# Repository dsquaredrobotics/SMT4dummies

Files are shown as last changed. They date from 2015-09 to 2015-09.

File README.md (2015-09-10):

# SMT4dummies

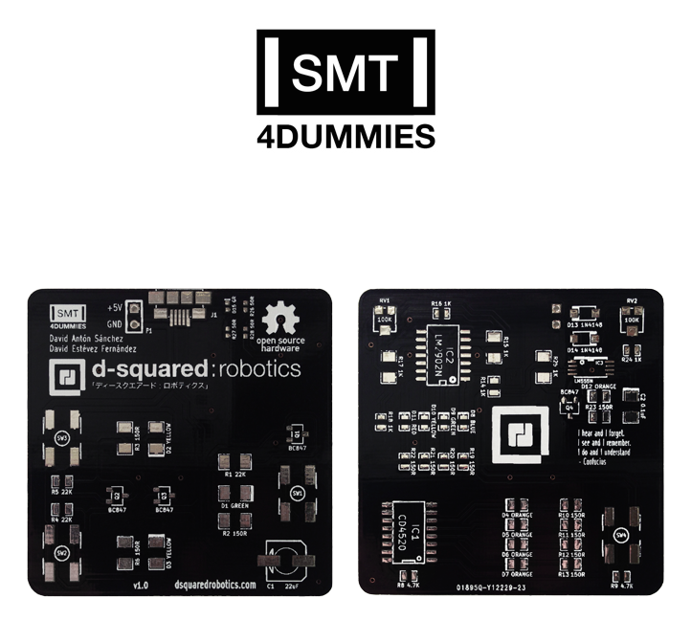
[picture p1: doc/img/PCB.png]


####Project

SMT4dummies is an SMT soldering practice kit.

###More info on [d-dquared:robotics](http://www.dsquaredrobotics.com/projects/smt4dummies/)

###Get one SMT4dummies kit on our [Store!](http://dsquaredrobotics.bigcartel.com/products)

Published under a GPLv3 lincense. More details on LICENSE.txt

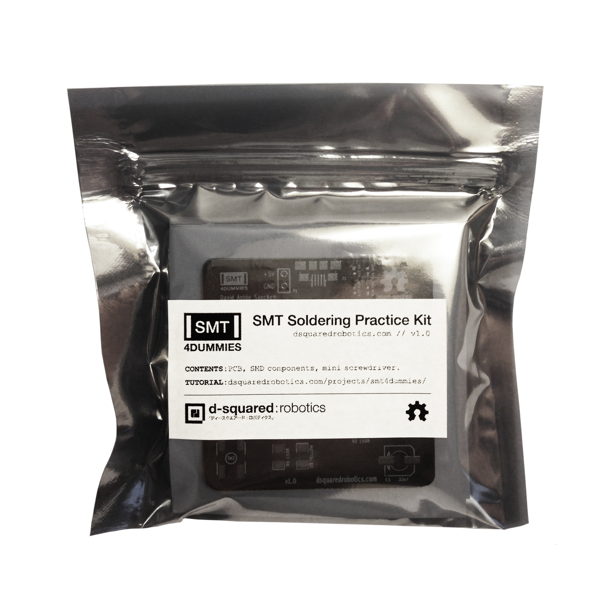
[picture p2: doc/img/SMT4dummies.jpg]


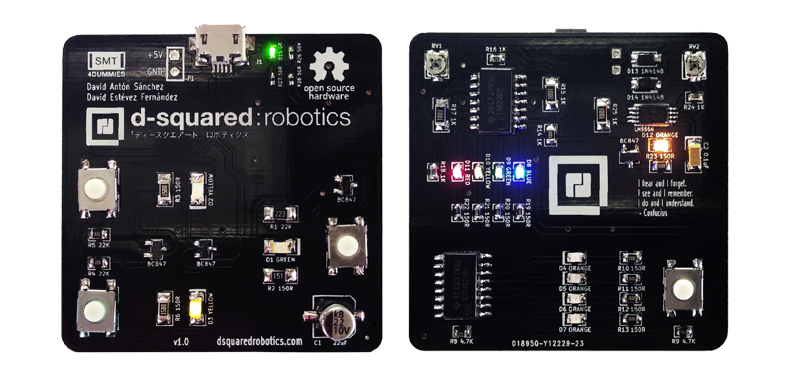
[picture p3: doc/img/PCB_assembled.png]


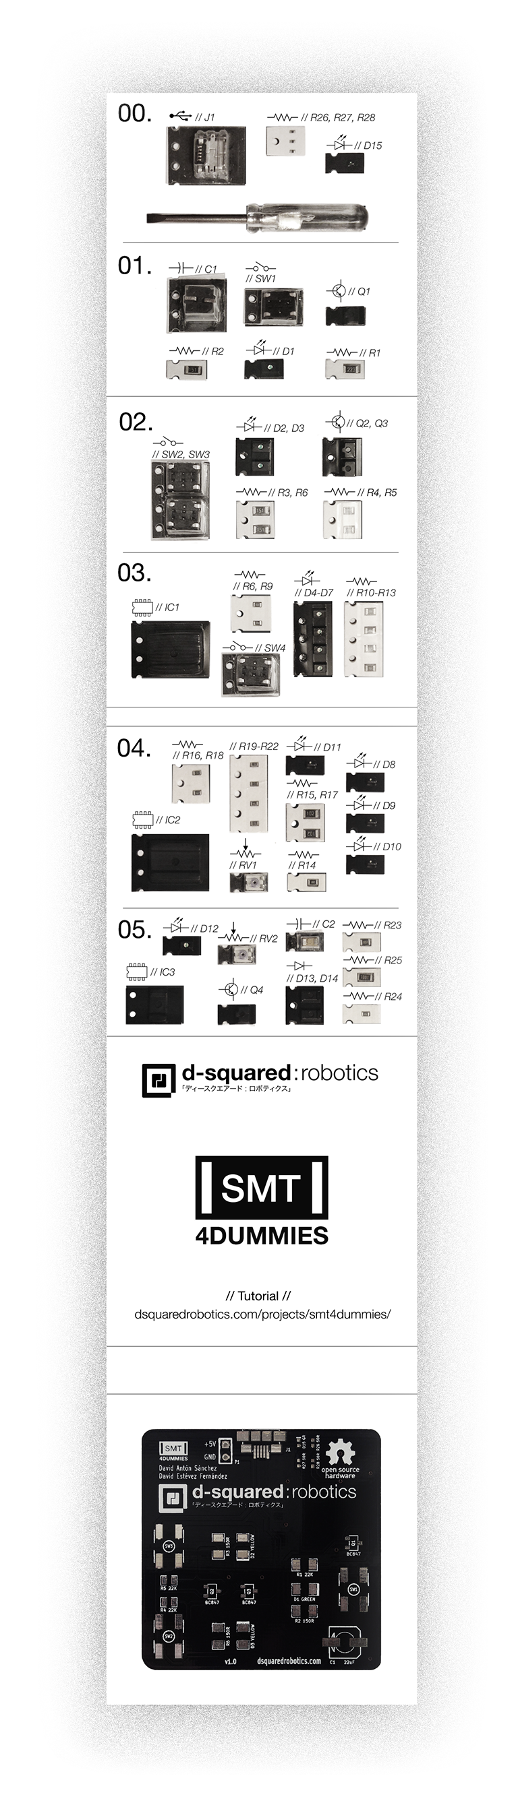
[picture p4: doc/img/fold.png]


#Get one SMT4dummies kit on our [Store!](http://dsquaredrobotics.bigcartel.com/products)

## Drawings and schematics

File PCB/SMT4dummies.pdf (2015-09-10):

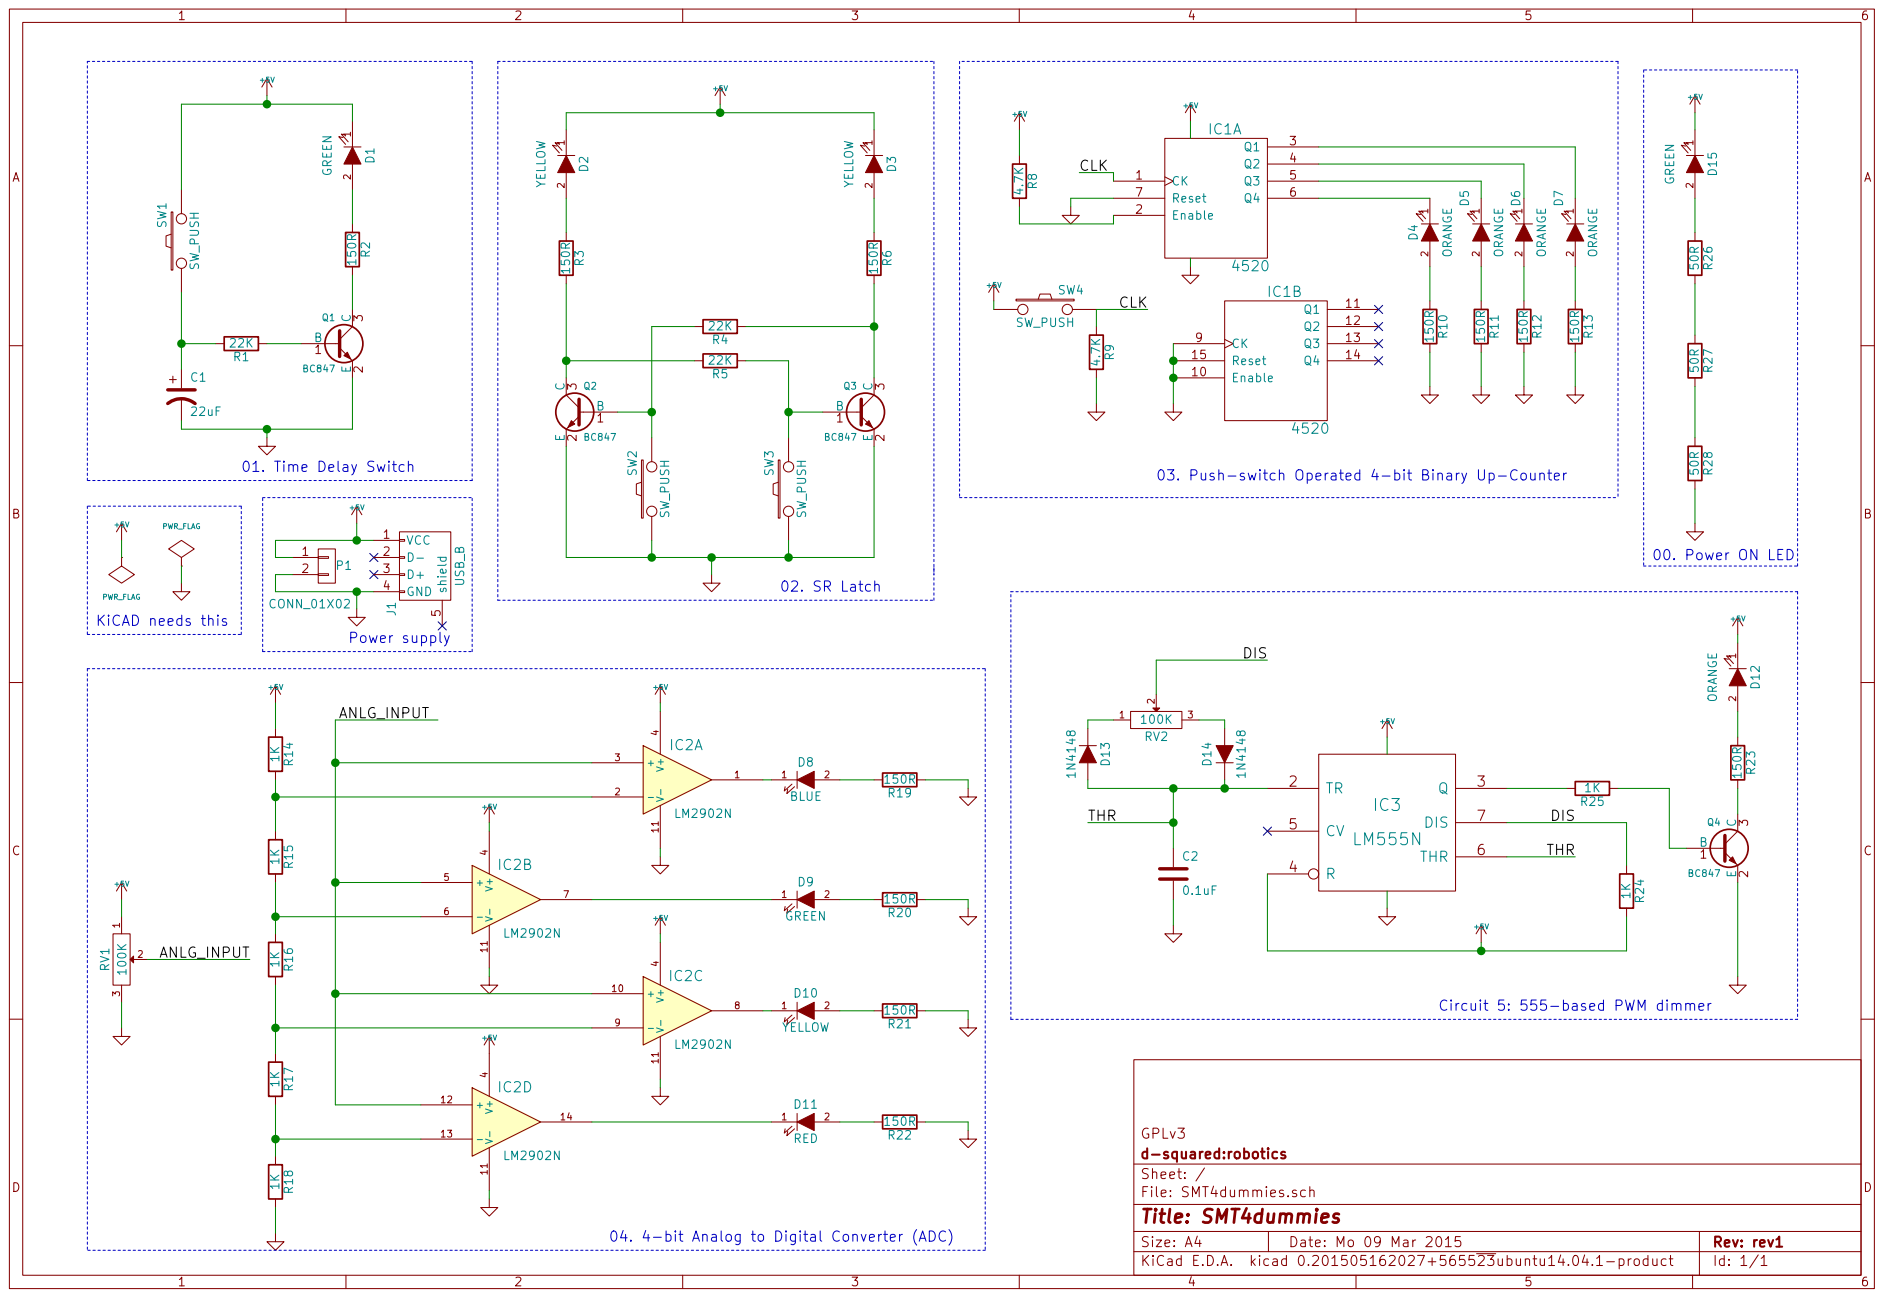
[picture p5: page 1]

04. 4-bit Analog to Digital Converter (ADC)

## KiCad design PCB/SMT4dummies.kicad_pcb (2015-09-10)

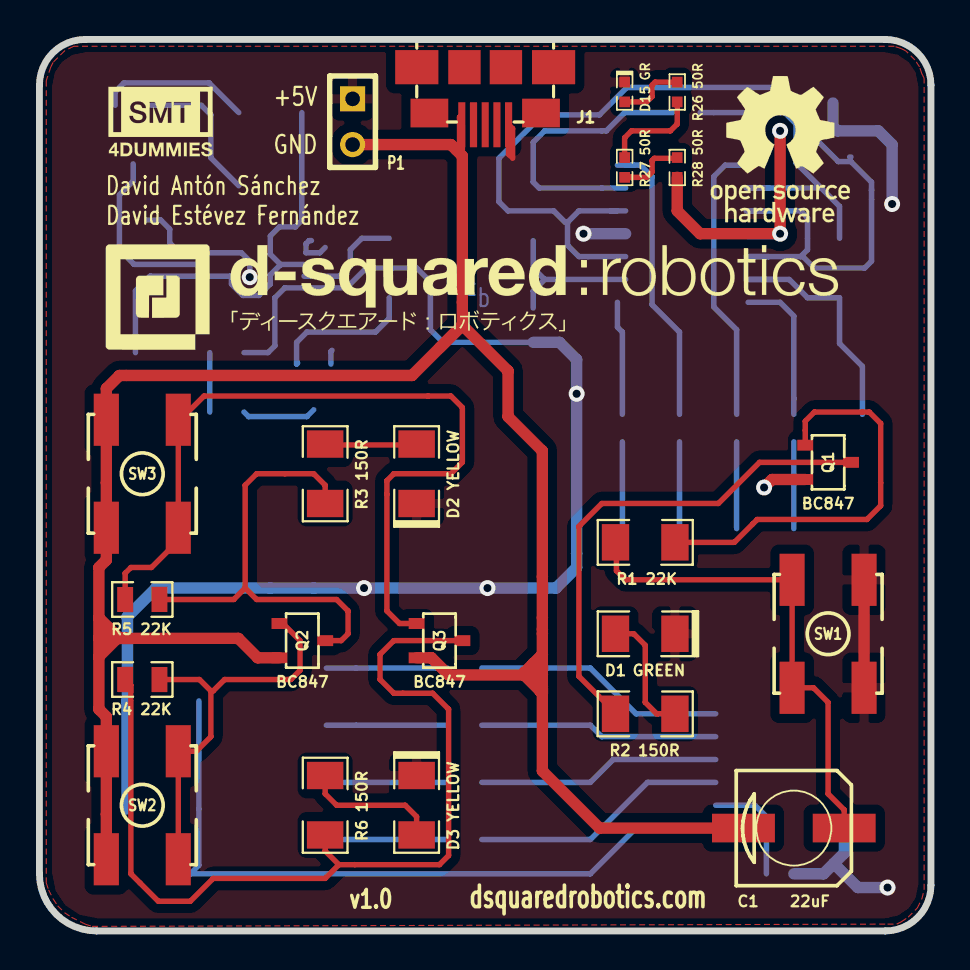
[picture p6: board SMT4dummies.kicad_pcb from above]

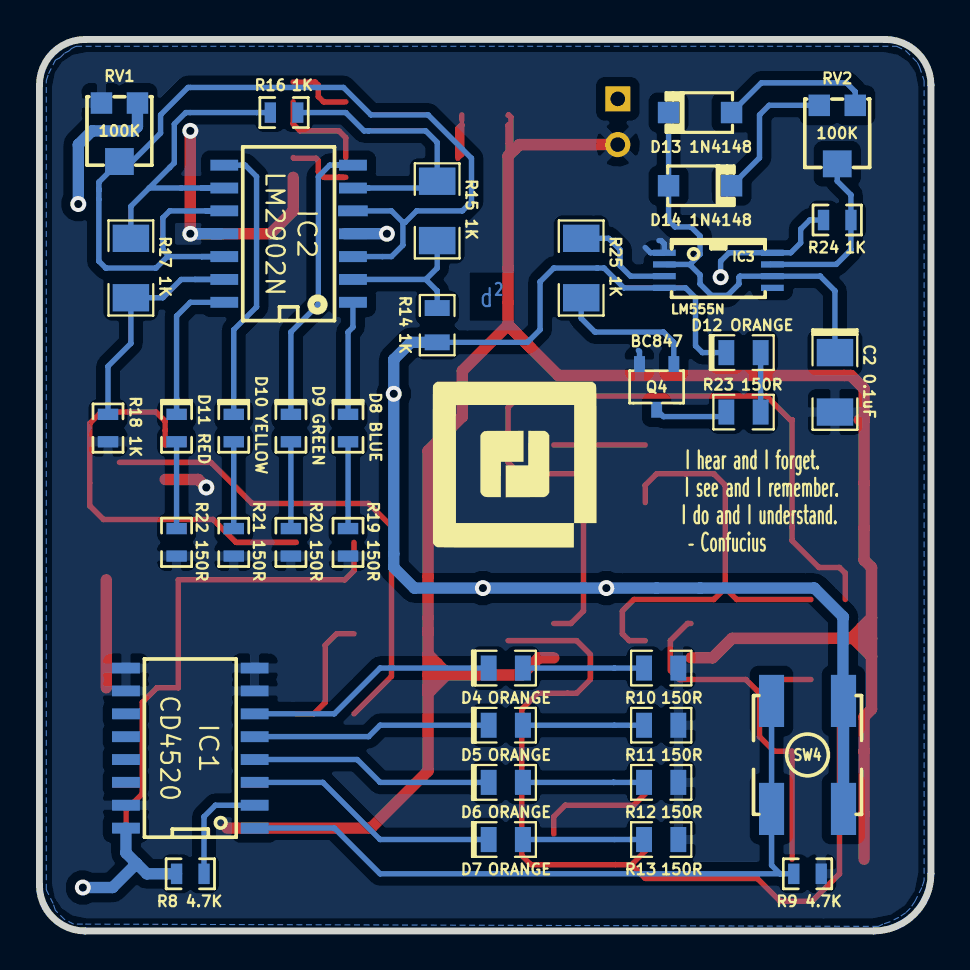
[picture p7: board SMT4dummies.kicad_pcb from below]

Board: 2 copper layers, 49.5 x 49.5 mm, 59 parts (37 on the bottom side), 46 nets.

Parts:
C1: 22uF; C1
C2: 0.1uF; SM1206_Opendous_LED(generic)
D1: GREEN; SM1206_Opendous_LED(generic)
D2, D3: YELLOW; SM1206_Opendous_LED(generic)
D4, D5, D6, D7, D12: ORANGE; SM0805_Opendous_LED(generic)
D8: BLUE; SM0603_Opendous_LED(generic)
D9: GREEN; SM0603_Opendous_LED(generic)
D10: YELLOW; SM0603_Opendous_LED(generic)
D11: RED; SM0603_Opendous_LED(generic)
D13, D14: 1N4148; SOD123(generic)
D15: GR; SM0402_LED(generic)
IC1: CD4520; SOIC16_NS_CD4520_BNSR
IC2: LM2902N; SOP14-LM2902NSR
IC3: LM555N; TSSOP-8_555_timer
J1: CONN_USB_microAB_ZX62-AB-5PA-11(custom)
P1: SIL-2
Q1, Q2, Q3, Q4: BC847; SOT23-3_Opendous
R1: 22K; SM1206(generic)
R2, R3, R6: 150R; SM1206(generic)
R4, R5: 22K; SM0805_Opendous(generic)
R8, R9: 4.7K; SM0603_Opendous(generic)
R10, R11, R12, R13, R23: 150R; SM0805_Opendous(generic)
R14: 1K; SM0805_Opendous(generic)
R15, R17, R25: 1K; SM1206(generic)
R16, R18, R24: 1K; SM0603_Opendous(generic)
R19, R20, R21, R22: 150R; SM0603_Opendous(generic)
R26, R27, R28: 50R; SM0402(generic)
RV1, RV2: 100K; POT_TC33X_3.8x3mm
SW1, SW2, SW3, SW4: Switch_SMT_TH_EVQ_TL59(generic)

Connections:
+5V: D1.1, D2.1, D3.1, D12.1, D15.1, IC1.16, IC2.4, IC3.4, IC3.8, J1.1, P1.1, R8.1, R14.1, R24.2, RV1.1, SW1.2, SW4.1
/ANLG_INPUT: IC2.3, IC2.5, IC2.10, IC2.12, RV1.2
/CLK: IC1.1, R9.1, SW4.2
/DIS: IC3.7, R24.1, RV2.2
/THR: C2.1, D13.1, D14.2, IC3.2, IC3.6
GND: C1.2, C2.2, IC1.7, IC1.8, IC1.9, IC1.10, IC1.15, IC2.11, IC3.1, J1.4, P1.2, Q1.2, Q2.2, Q3.2, Q4.2, R9.2, R10.2, R11.2, R12.2, R13.2, R18.2, R19.1, R20.1, R21.1, R22.1, R28.2, RV1.3, SW2.1, SW3.1
unnamed: D14.1, RV2.3
unnamed: D12.2, R23.1
unnamed: IC3.3, R25.2
unnamed: IC2.2, R14.2, R15.1
unnamed: IC2.13, R17.2, R18.1
unnamed: D8.2, R19.2
unnamed: Q1.1, R1.1
unnamed: D1.2, R2.1
unnamed: Q3.1, R5.1, SW3.2
unnamed: D3.2, R6.1
unnamed: Q2.1, R4.2, SW2.2
unnamed: Q4.3, R23.2
unnamed: IC1.2, R8.2
unnamed: D8.1, IC2.1
unnamed: D9.1, IC2.7
unnamed: IC2.6, R15.2, R16.1
unnamed: D9.2, R20.2
unnamed: D11.2, R22.2
unnamed: D11.1, IC2.14
unnamed: D10.1, IC2.8
unnamed: D10.2, R21.2
unnamed: D13.2, RV2.1
unnamed: IC2.9, R16.2, R17.1
unnamed: R27.2, R28.1
unnamed: R26.2, R27.1
unnamed: D15.2, R26.1
unnamed: Q1.3, R2.2
unnamed: Q2.3, R3.2, R5.2
unnamed: D6.1, IC1.4
unnamed: D4.1, IC1.6
unnamed: Q3.3, R4.1, R6.2
unnamed: D2.2, R3.1
unnamed: C1.1, R1.2, SW1.1
unnamed: D7.1, IC1.3
unnamed: Q4.1, R25.1
unnamed: D5.1, IC1.5
unnamed: D6.2, R12.1
unnamed: D4.2, R10.1
unnamed: D7.2, R13.1
unnamed: D5.2, R11.1

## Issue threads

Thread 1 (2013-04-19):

Bugs on beta version (v1.0b1)

David-Estevez, 2013-04-19:
This is a list of errors found on the beta board:
## Errors that *MUST* be fixed:
- [ ] Footprint of SOT-23 transistor is not correct ( base and emitter exchanged ).
- [ ] Footprint of ICs does not fit completely.
- [ ] 0402 footprint is 'not suitable' for hand-soldering. (Even though we managed to solder the resistor).

## Not-so-important errors:
- [ ] Holes for switches are not needed
- [ ] Holes for USB connector does not fit the connector itself
- [ ] Bigger font for quote
- [ ] Values on silkscreen

Closed 2015-03-09.

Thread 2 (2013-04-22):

Less critical function for 0402 components

David-Estevez, 2013-04-22:
Currently the 0402 resistors play a critical role in the circuits.

It is preferable that they form an independent circuit
whose functionality is optional and not critical.

Closed 2015-03-09.

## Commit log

2012-09-11 KiCad project structure created
    [SMT4dummies.sch, sideA.sch, sideB.sch]
2012-09-12 Started counter circuit
    [sideB.sch]
2012-09-12 Binary counter circuit finished
    [sideB.sch]
2012-09-13 ADC circuit added to schematic
    [sideB.sch]
2012-09-13 555 added, not finished. Power supply added.
    [sideB.sch]
2012-09-14 Two choices added to 555 circuit.
    [sideB.sch]
2012-09-16 SideA with 2 circuits ERC checked
    [sideA.sch]
2012-09-16 Misconnection fixed
    [sideA.sch]
2012-09-18 Annotations and ERC error pending
    [sideA.sch]
2012-09-18 Annotated and ERC checked
    [sideA.sch]
2012-09-18 555 design finished.
    [sideB.sch]
2012-09-18 Added USB power supply, ERC performed
    [sideA.sch]
2012-09-19 Schematic Annotated
    [sideB.sch]
2012-09-22 PCB test uploaded. Testing dimensions
    [SMT4dummies.brd]
2012-09-30 First values added.
    [sideB.sch]
2013-02-06 Some footprints assigned.
2013-02-13 555 circuit changed.
    [sideB.sch]
2013-02-14 Potentiometer footprints added.
    [sideB.sch]
2013-02-14 Some footprints added to side A.
2013-02-14 More footprints added.
2013-02-19 Op-amp footprint changed.
2013-02-25 NPN transistors changed
    [sideA.sch]
2013-02-25 Capacitor footprint added
2013-02-25 Merged both sides
    [SMT4dummies.sch]
2013-02-26 Edited transistor pinout. Created new compoment NPN.
    [SMT4dummies.sch, sideA.sch, sideB.sch]
2013-02-26 Changed footprints of LEDs
2013-02-26 LED resistors value (150ohm) added to schematics.
    [sideA.sch, sideB.sch]
2013-02-27 Added values for resistors.
    [sideB.sch]
2013-02-27 All components spitted on the board.
    [$savepcb.brd, SMT4dummies.brd, sideA.sch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]
2013-02-27 Some little things placed.
    [SMT4dummies.brd]
2013-02-27 Fixed capacitor module, some advances on the board
    [SMT4dummies.brd]
2013-03-01 Added design rules.
    [SMT4dummies.brd]
2013-03-02 Fixed netlist.
    [SMT4dummies.brd]
2013-03-02 555 circuit routed.
    [SMT4dummies.brd]
2013-03-02 Counter (4520) circuit routed.
    [SMT4dummies.brd]
2013-03-02 Op-amp routed. Some trancks changed.
    [SMT4dummies.brd]
2013-03-02 Added some space to the upper part of the board.
    [SMT4dummies.brd]
2013-03-02 Placed power connectors and free space outline.
    [SMT4dummies.brd]
2013-03-04 Modified counter.
    [SMT4dummies.brd, SMT4dummies.sch, sideB.sch]
2013-03-04 Some improvements on the board
    [SMT4dummies.brd]
2013-03-04 Partial routing of sideA
    [SMT4dummies.brd]
2013-03-04 Ruted GND connections of side A. Added copper layer to front.
    [SMT4dummies.brd]
2013-03-05 Power traces of side B added.
    [SMT4dummies.brd]
2013-03-05 Some tracks fixed.
    [SMT4dummies.brd]
2013-03-05 Everything routed except Vcc on USB.
    [SMT4dummies.brd]
2013-03-05 Issue with vias fixed.
    [SMT4dummies.brd]
2013-03-11 Track problems solved.
    [SMT4dummies.brd, SMT4dummies.sch]
2013-03-11 Rounded edges. (and added weird thing)
    [SMT4dummies.brd]
2013-03-13 Fixed boundary-crossing track
    [$savepcb.brd, SMT4dummies.brd]
2013-03-13 Final layout, ERC performed
    [SMT4dummies.brd]
2013-03-14 .mod files created for the capacitor and 1206 resistor
2013-03-14 Custom library.mod created
    [SMT4dummies.brd]
2013-03-14 Test holes added
    [SMT4dummies.brd]
2013-03-14 Weird ERC error fixed
    [SMT4dummies.brd]
2013-03-14 Drills removed, text added, copper on corners rounded.
    [SMT4dummies.brd, SMT4dummies.sch]
2013-03-15 Added revision number to silkscreen.
    [SMT4dummies.brd]
2013-03-18 Logos added, relocation of components
    [SMT4dummies.brd]
2013-03-18 SMT4dummies logo added, some improvements on the silkscreen
    [SMT4dummies.brd, SMT4dummies.sch]
2013-03-21 Fixed pull-up resistor postion on schematic.
    [SMT4dummies.sch]
2013-03-21 R8 resistor added how it was supposed to be added.
2013-03-23 Minor fixes and layout modification, TSSOP for the 555 timer
    [SMT4dummies.brd]
2013-03-23 Board ready for the majority of the footprints to be downsized
    [SMT4dummies.brd]
2013-03-24 Potentiometer vias changed. DRC rules updated.
    [$savepcb.brd, SMT4dummies.brd]
2013-03-24 Gerbers and README added.
    [-Back.gbl, -Front.gtl, -Mask_Back.gbs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]
2013-03-25 Smaller components added, ERC performed
    [SMT4dummies.brd]
2013-03-25 Saving before upgrading KiCAD version.
    [SMT4dummies.brd]
2013-03-25 Updated KiCAD version files.
    [-Back.gbl, -Front.gtl, -Mask_Back.gbs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]
2013-03-25 Moved transistor overlayed by logo silkscreen
    [SMT4dummies.brd]
2013-03-25 Gerbers generated, pad mask clearance 0.01mm
    [SMT4dummies.brd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]
2013-03-25 Fixed NPTH USB hole
    [SMT4dummies.brd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]
2013-03-25 Renamed Gerber files
    [SMT4dummies-NPTH.drl, SMT4dummies.GBL, SMT4dummies.GBO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]
2013-06-08 Schematic fixed. Values added. Netlist updated.
    [SMT4dummies.sch]
2013-06-14 Changed 0402 resistors to 0603
    [SMT4dummies.brd]
2013-07-01 Transistor polarity error fixed
    [SMT4dummies.brd, SMT4dummies.sch]
2013-07-01 Resistor footprints changed 0402 to 0603
    [SMT4dummies.brd]
2013-07-02 Power tracks changed.
    [SMT4dummies.brd]
2013-07-02 Diode SOD123 footprint fixed
    [SMT4dummies.brd]
2013-07-02 Push switch holes removed (unnecessary), re-routing and error fixed
    [SMT4dummies.brd]
2013-07-03 Connector changed, USB Mini B to USB Micro B
    [SMT4dummies.brd]
2013-07-03 LED silkscreen polarity added, sikscreen corrections and minor fixes
    [SMT4dummies.brd]
2013-07-04 Added TSSOP8 footprint to custom library.
2013-07-04 Erased SideA and sideB legacy files
    [sideA.sch, sideB.sch]
2013-07-04 Added footprint of SOP14 for the op-amp to Custom Lib
2014-08-13 Some changes made to Custom Library
    [SMT4dummies.brd]
2015-09-10 Update folder structure
    [SMT4dummies.kicad_pcb, SMT4dummies.sch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]
